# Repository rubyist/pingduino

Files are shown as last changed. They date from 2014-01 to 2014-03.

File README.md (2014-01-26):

# Pingduino

Pingduino an Arduino based score keeper for games of ping pong. This repository
contains everything you need to build your own. Except the hardware, of course!

## Features

Pingduino is set up such that there are two scoring buttons and a display. I've
mounted the buttons underneath my ping pong table, one on each side. When a player
scores, they press their button.

The display is built to show each score and an indicator showing whose who is
currently serving. The serve indicator updates automatically as scores are input.

The program code contains game winning logic, meaning it knows the rules of
ping pong and will indicate the winner when it detects the game has been won.

Upon detecting a win, Pingduino will play a victory song and flash the serve
indicator of the game winner.

If Pingduino detects no activity for 20 minutes it will automatically turn off
the display lights and the scoring button lights. Pressing any button will wake
the display and Pingduino will pick up where you left off.

## Usage Instructions

Once you've built and installed Pingduino it's time to play! Simply start playing
ping pong. Pingduino lets you know which player should serve. If you score, press
your button. Eventually somebody will win!

Once the game has been won, the player who will serve the next game will reset
the system by doing a long press (press and hold for a second or two) on their
button.

## Building Your Own

Building your own Pingduino should be easy. It's my first Arduino project and
I'm a pretty novice hardware hacker. This repository contains the program code
to load onto the Arduino as well as schematics, a parts list, and a PCB layout
should you choose to go beyond the breadboard. Once completed I'll post a link
to pictures of my build process.

### Display

I was initially going to use some giant ~8" 7-segment LEDs for the score display,
however the two that I found that were big enough were too expensive and not well
built or out of stock. I decided to build my own large 7-segment displays out of
ping pong balls and individual LEDs. Once assembled, these behave pretty much like
regular 7-segment displays and I'm driving them with 4 shift registers chained
together.

I've kept the display logic code fairly encapsulated so that you can be free to
implement whatever kind of display you'd like. My intitial prototypes were built
using an LCD display.

### Scoring Buttons

There are scoring buttons mounted under each side of the table. I used some
[big dome push buttons](https://www.sparkfun.com/products/11275) from Sparkfun.
These are pretty big, you could certainly get away with much smaller buttons,
but I ordered them so I rolled with it.

To connect the buttons to the main module I used some 1/8" audio jacks and cables.
These are readily available, cheap, and perfectly support the button signal and
a line to light the LED in the button.

To mount the buttons under the table I designed and printed some simple boxes.
You can find the openscad and stl files in the models directory. I printed these
on a Makerbot Replicator 2. It's just a box that goes under a table so you can
get away with printing at a lower resolution (0.3mm), but be aware that the hole
for the audio jack will probably have to be drilled and smoothed out some before
it fits nicely.

## Contributing

Got an idea for improving Pingduino? Found a bug? I'd love to know about it!
Simply file an issue or open a pull request here on GitHub.

If you build and use a Pingduino I'd love to know about it, especially if you
come up with a different kind of display.

## License

Everything in this repo is released under the MIT license.

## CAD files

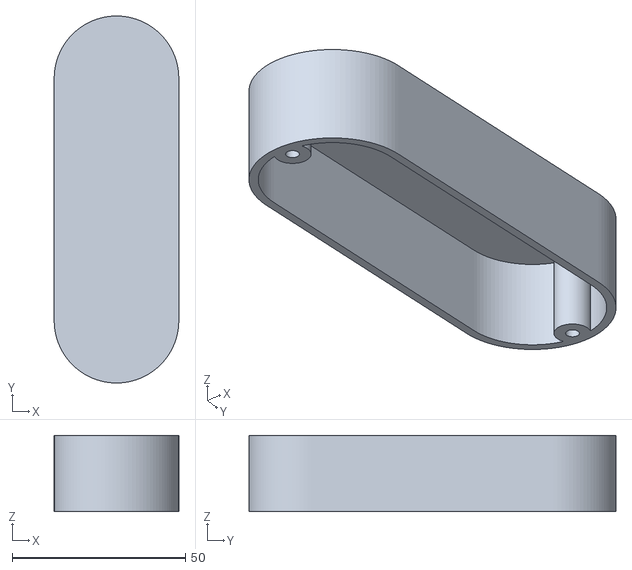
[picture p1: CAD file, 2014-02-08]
models/segment.stl
36.0 x 106.0 x 22.0

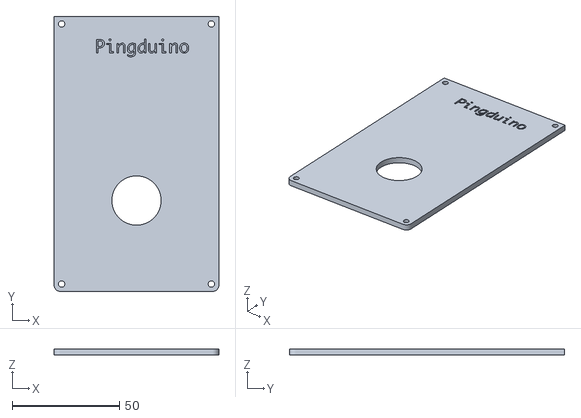
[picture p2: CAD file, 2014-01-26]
models/switch-mount-cover.stl
77.0 x 128.5 x 3.00

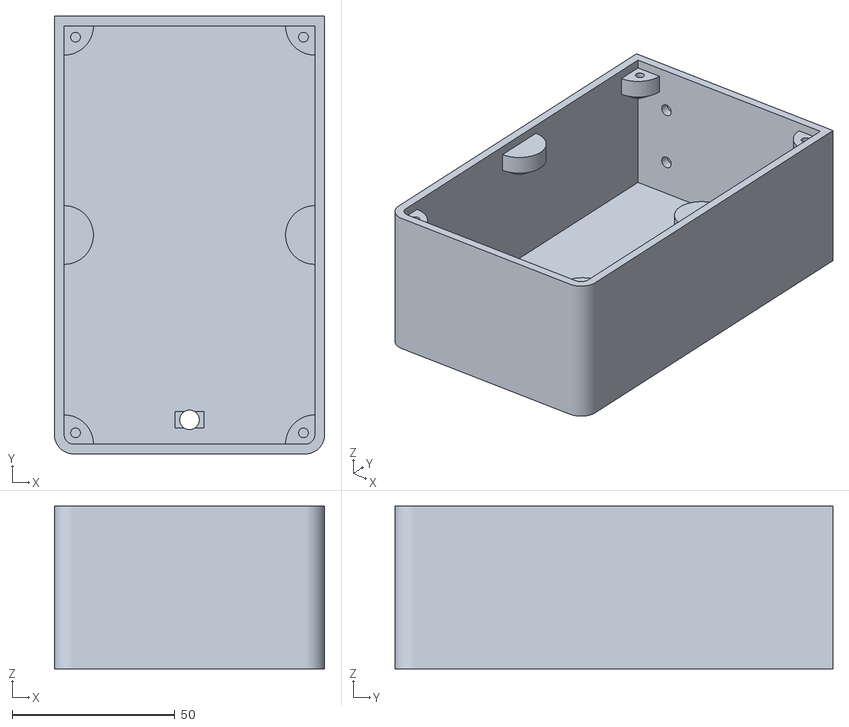
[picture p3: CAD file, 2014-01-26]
models/switch-mount.stl
83.0 x 134.5 x 50.0

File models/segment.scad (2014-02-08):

radius = 18;
height = 22;
length = 70;
wall   =  2;

$fn=100;

module post() {
    difference() {
        cylinder(r=4, h=height-wall);
        cylinder(r=1.5, h=10);
    }
}

difference() {
    hull() {
        cylinder(r=radius, h=height);

        translate([0, length, 0])
        cylinder(r=radius, h=height);
    }

    hull() {
        translate(0, wall, 0)
        cylinder(r=radius-wall, h=height-wall);

        translate([0, length, 0])
        cylinder(r=radius-wall, h=height-wall);
    }
}

translate([0, -(radius+wall)/2-2*wall, 0])
post();

translate([0, length + ((radius+wall)/2+2*wall), 0])
post();

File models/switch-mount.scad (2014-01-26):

// This box is the housing for the scoring buttons that get mounted
// under the pingpong table. The buttons I used are these:
// https://www.sparkfun.com/products/11275
// In hindsight, these buttons are rather large. You could use smaller
// buttons and adjust some of these values accordingly.

// The overall radius of the button. The datasheet reports 100mm, but
// mine both measure 98.
button_radius = 49;

// The radius of the hole the button back needs.
hole_radius = 11.5;

// There's a bar on the front of my table that is 40mm high
table_padding = 40;

// I want 30mm around the button's hole
bottom_padding = 30;
extra_padding = 4;

// The thickness of the box walls
wall_thickness = 3;

// Dimensions for the overall box
mount_height = table_padding + extra_padding + button_radius + hole_radius + bottom_padding;
mount_depth = 50;
mount_width = (hole_radius * 2) + (bottom_padding * 2);

$fn=100;
font = "monaco.dxf";

// Comment or uncomment the body or cover, depending on which you need to render

// Body
union() {
    difference() {
        bottom();
        // You can inscribe something here. I print the box at lower resolution (.3mm), it
        // comes out OK but not very good looking. Higher res looks better.
        // name();
    }
    
    difference() {
        sides();
        cover_screws();
        mount_screws();
    }
}

// Cover
/*
difference() {
    translate([0, 0, mount_depth-wall_thickness])
    cover();
    cover_screws();
    // Remove this line if you don't want the project's name on the cover
    project();
}
*/

// You shouldn't have to configure anything below this, except maybe text
// attributes at the bottom if you're putting your own text in it.

module bottom() {
    difference() {
    hull() {
        // lower left
        translate([wall_thickness*2, wall_thickness*2, 0])
        cylinder(r=wall_thickness*2, h=wall_thickness);
        
        // lower right
        translate([mount_width-(wall_thickness*2), wall_thickness*2, 0])
        cylinder(r=wall_thickness*2, h=wall_thickness);

        // upper right
        translate([mount_width-(wall_thickness*2), mount_height-(wall_thickness*2), 0])
        cube(size=[wall_thickness*2, wall_thickness*2, wall_thickness]);
        
        // upper left
        translate([0, mount_height-(wall_thickness*2), 0])
        cube(size=[wall_thickness*2, wall_thickness*2, wall_thickness]);
    }

    union() {
        translate([mount_width/2, wall_thickness+7.5, -1])
        cylinder(r=3, h=wall_thickness+2);

        translate([mount_width/2-4.5, wall_thickness+7.5-2.5, wall_thickness-.8])
        cube(size=[9, 5, 1]);
    }
    }
}

module sides() {
    difference() {
        hull() {
            // lower left
            translate([wall_thickness*2, wall_thickness*2, 0])
            cylinder(r=wall_thickness*2, h=mount_depth);
            
            // lower right
            translate([mount_width-(wall_thickness*2), wall_thickness*2, 0])
            cylinder(r=wall_thickness*2, h=mount_depth);

            // upper right
            translate([mount_width-(wall_thickness*2), mount_height-(wall_thickness*2), 0])
            cube(size=[wall_thickness*2, wall_thickness*2, mount_depth]);
            
            // upper left
            translate([0, mount_height-(wall_thickness*2), 0])
            cube(size=[wall_thickness*2, wall_thickness*2, mount_depth]);
        }
        
        hull() {
            // lower left
            translate([wall_thickness*2, wall_thickness*2, 0])
            cylinder(r=wall_thickness, h=mount_depth+1);
            
            // lower right
            translate([mount_width-(wall_thickness*2), wall_thickness*2, 0])
            cylinder(r=wall_thickness, h=mount_depth+1);

            // upper right
            translate([mount_width-(wall_thickness*2), mount_height-(wall_thickness*2), 0])
            cube(size=[wall_thickness, wall_thickness, mount_depth+1]);
            
            // upper left
            translate([wall_thickness, mount_height-(wall_thickness*2), 0])
            cube(size=[wall_thickness, wall_thickness, mount_depth+1]);
        }
    }

    intersection() {
        translate([wall_thickness, wall_thickness, 0])
        cube([mount_width-(wall_thickness*2), mount_height-(wall_thickness*2), mount_depth]);

        union() {
            translate([wall_thickness, wall_thickness, mount_depth-6-wall_thickness])
            cylinder(r=9, h=6);
            translate([wall_thickness, wall_thickness, mount_depth-10-wall_thickness])
            cylinder(r1=3, r2=9, h=4);

            translate([wall_thickness, mount_height/2, mount_depth-6-wall_thickness])
            cylinder(r=9, h=6);
            translate([wall_thickness, mount_height/2, mount_depth-10-wall_thickness])
            cylinder(r1=3, r2=9, h=4);

            translate([mount_width-wall_thickness, wall_thickness, mount_depth-6-wall_thickness])
            cylinder(r=9, h=6);
            translate([mount_width-wall_thickness, wall_thickness, mount_depth-10-wall_thickness])
            cylinder(r1=3, r2=9, h=4);

            translate([mount_width-wall_thickness, mount_height/2, mount_depth-6-wall_thickness])
            cylinder(r=9, h=6);
            translate([mount_width-wall_thickness, mount_height/2, mount_depth-10-wall_thickness])
            cylinder(r1=3, r2=9, h=4);

            translate([mount_width-wall_thickness, mount_height-wall_thickness, mount_depth-6-wall_thickness])
            cylinder(r=9, h=6);
            translate([mount_width-wall_thickness, mount_height-wall_thickness, mount_depth-10-wall_thickness])
            cylinder(r1=3, r2=9, h=4);

            translate([wall_thickness, mount_height-wall_thickness, mount_depth-6-wall_thickness])
            cylinder(r=9, h=6);
            translate([wall_thickness, mount_height-wall_thickness, mount_depth-10-wall_thickness])
            cylinder(r1=3, r2=9, h=4);
        }
    }
}

module cover() {
    hole_center = mount_height - table_padding - button_radius;

    difference() {
        hull() {
            // lower left
            translate([wall_thickness*2, wall_thickness*2, 0])
            cylinder(r=wall_thickness, h=wall_thickness);
            
            // lower right
            translate([mount_width-(wall_thickness*2), wall_thickness*2, 0])
            cylinder(r=wall_thickness, h=wall_thickness);
            
            // upper right
            translate([mount_width-(wall_thickness*2), mount_height-(wall_thickness*2), 0])
            cube(size=[wall_thickness, wall_thickness, wall_thickness]);
            
            // upper left
            translate([wall_thickness, mount_height-(wall_thickness*2), 0])
            cube(size=[wall_thickness, wall_thickness, wall_thickness]);
        }
        
        translate([mount_width/2, hole_center, -1])
        cylinder(r=hole_radius, h=wall_thickness*2);
    }

    // Fake button
    // translate([mount_width/2, hole_center, 5])
    // cylinder(r=button_radius, h=20);
}

module cover_screws() {
    translate([wall_thickness+3.5, wall_thickness+3.5, mount_depth/2])
    cylinder(r=1.5, h=30);

    translate([mount_width-wall_thickness-3.5, wall_thickness+3.5, mount_depth/2])
    cylinder(r=1.5, h=30);

    translate([mount_width-wall_thickness-3.5, mount_height-wall_thickness-3.5, mount_depth/2])
    cylinder(r=1.5, h=30);

    translate([wall_thickness+3.5, mount_height-wall_thickness-3.5, mount_depth/2])
    cylinder(r=1.5, h=30);
}

module mount_screws() {
    spacing = 15;
    
    translate([spacing, mount_height, spacing])
    rotate([90, 0, 0])
    cylinder(r=2, h=wall_thickness+2);

    translate([spacing, mount_height, mount_depth-spacing])
    rotate([90, 0, 0])
    cylinder(r=2, h=wall_thickness+2);

    translate([mount_width-spacing, mount_height, mount_depth-spacing])
    rotate([90, 0, 0])
    cylinder(r=2, h=wall_thickness+2);

    translate([mount_width-spacing, mount_height, spacing])
    rotate([90, 0, 0])
    cylinder(r=2, h=wall_thickness+2);
}

// Text
module letter(l, h=100, i=0) {
    union() {
        linear_extrude(height=h) import(font, layer=l[i]);
        translate([dxf_dim(file=font, name="advx", layer=l[i]), dxf_dim(file=font, name="advy", layer=l[i]), 0])
        child();
    }
}

module word(wrd, h=100, i=0) {
    if (i < len(wrd)) {
        letter(wrd, h, i) word(wrd, h, i+1);
    } else {
        child();
    }
}


module name() {
    translate([18.5, mount_height - 20, wall_thickness-1.5])
    scale(0.002)
    word("YourTextHere", 1000);
}

module project() {
    translate([22, mount_height-20, mount_depth-1.5])
    scale(0.002)
     word("Pingduino", 1000);
}

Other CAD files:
models/monaco.dxf

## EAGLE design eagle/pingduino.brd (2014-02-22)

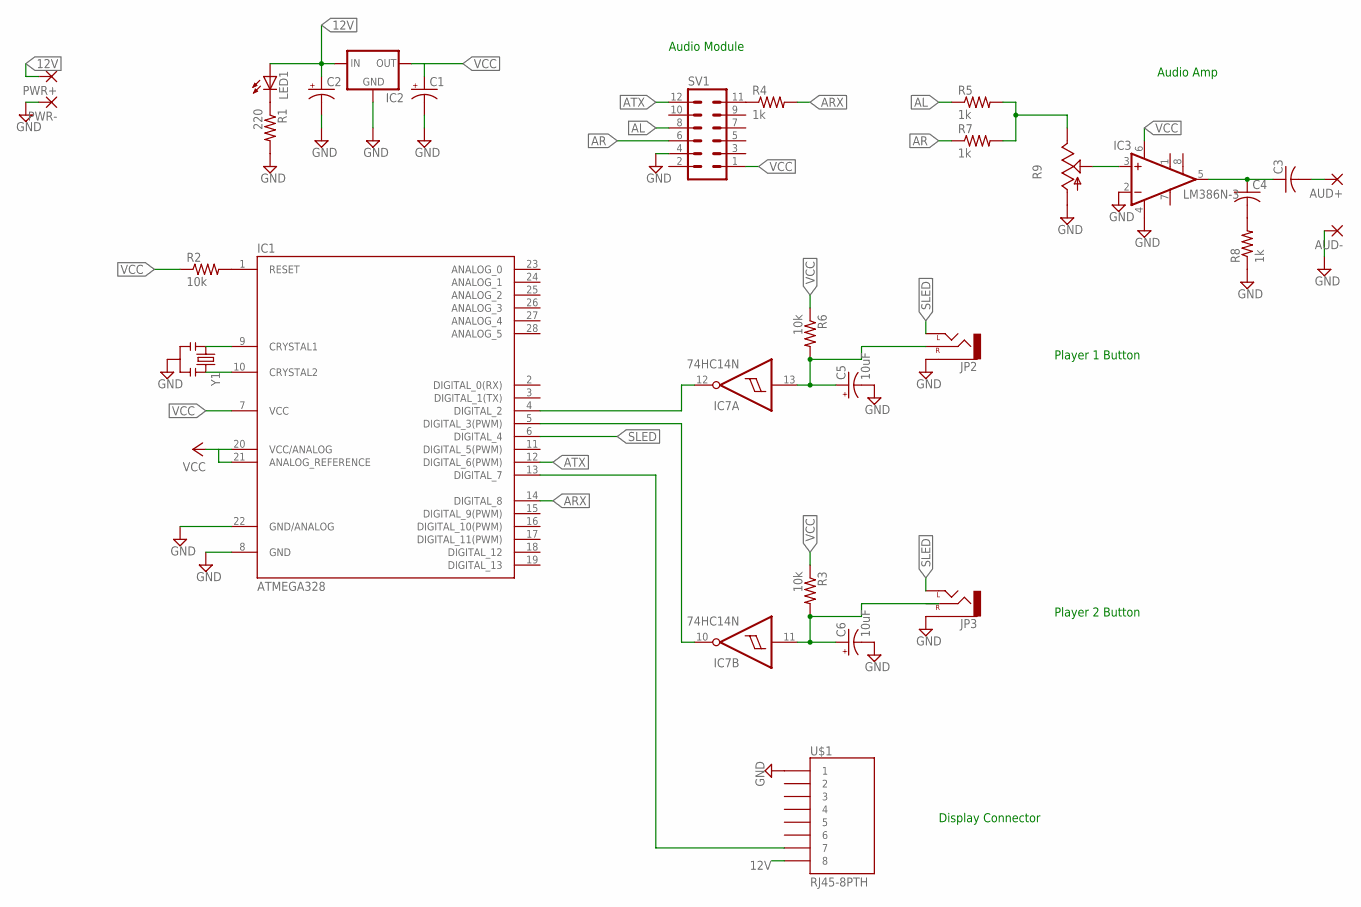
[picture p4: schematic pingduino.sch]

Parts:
AUD+: WIREPAD2,15/1,0; 2,15/1,0
AUD-: WIREPAD2,15/1,0; 2,15/1,0
C1, C2: CAP_POLPTH2; CPOL-RADIAL-10UF-25V
C3, C4: C-US050-024X044; C050-024X044
C5, C6: 10uF; CPOL-RADIAL-10UF-25V
IC1: ATMEGA328; DIL28-3
IC2: V_REG_78XX-TO-220; TO-220-ALT
IC3: LM386N-3; DIL08
IC7: 74HC14N; DIL14
JP2, JP3: AUDIO-JACKPTH; AUDIO-JACK
LED1: LED3MM
PWR+: WIREPAD2,15/1,0; 2,15/1,0
PWR-: WIREPAD2,15/1,0; 2,15/1,0
R1: 220; 0204/7
R2, R3, R6: 10k; 0204/7
R4, R5, R7, R8: 1k; 0204/7
R9: TRIM_US-B25U; B25U
SV1: MA06-2
U$1: RJ45-8PTH; RJ45-8
Y1: RESONATORPTH; RESONATOR-PTH

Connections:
12V: C2.1 (+), IC2.IN, LED1.A, PWR+.1, U$1.8
AL: R5.1, SV1.8
AR: R7.1, SV1.6
ARX: IC1.13 (DIGITAL_7), IC1.14 (DIGITAL_8), R4.2, U$1.7
ATX: IC1.12 (DIGITAL_6(PWM)), SV1.12
GND: AUD-.1, C1.2 (-), C2.2 (-), C5.2 (-), C6.2 (-), IC1.8 (GND), IC1.22 (GND/ANALOG), IC2.GND, IC3.2 (-IN), IC3.4 (GND), IC7.7 (GND), JP2.SLEEVE, JP3.SLEEVE, PWR-.1, R1.2, R8.1, R9.A, SV1.4, U$1.1, Y1.2
unnamed: IC1.10 (CRYSTAL2), Y1.3
unnamed: IC1.9 (CRYSTAL1), Y1.1
unnamed: LED1.K (C), R1.1
unnamed: IC1.1 (RESET), R2.2
unnamed: IC1.4 (DIGITAL_2), IC7.12 (O)
unnamed: C6.1 (+), IC7.11 (I), R3.2
unnamed: IC1.5 (DIGITAL_3(PWM)), IC7.10 (O)
unnamed: C5.1 (+), IC7.13 (I), JP2.RING (RIGHT), R6.2
unnamed: R4.1, SV1.11
unnamed: R5.2, R7.2, R9.E
unnamed: IC3.3 (+IN), R9.S
unnamed: C3.1, C4.1, IC3.5 (OUT)
unnamed: C4.2, R8.2
unnamed: AUD+.1, C3.2
SLED: IC1.6 (DIGITAL_4), JP2.TIP (LEFT), JP3.TIP (LEFT)
VCC: C1.1 (+), IC1.7 (VCC), IC1.20 (VCC/ANALOG), IC1.21 (ANALOG_REFERENCE), IC2.OUT, IC3.6 (VS), IC7.14 (VCC), R2.1, R3.1, R6.1, SV1.1

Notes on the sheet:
Player 1 Button
Player 2 Button
Display Connector
Audio Module
Audio Amp

Board: 2 copper layers, 29 parts (0 on the bottom side), 22 nets, no tracks yet.

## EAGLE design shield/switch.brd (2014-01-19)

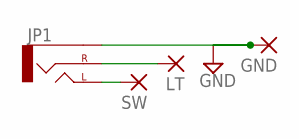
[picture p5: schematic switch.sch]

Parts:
GND: 2,15/1,0
JP1: AUDIO-JACKPTH; AUDIO-JACK
LT: 2,15/1,0
SW: 2,15/1,0

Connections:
GND: GND.1, JP1.SLEEVE
unnamed: JP1.RING (RIGHT), LT.1
unnamed: JP1.TIP (LEFT), SW.1

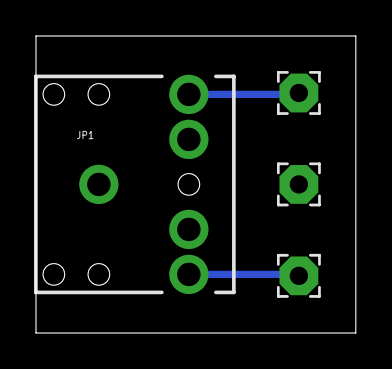
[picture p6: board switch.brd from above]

Board: 2 copper layers, 17.8 x 16.5 mm, 4 parts (0 on the bottom side), 3 nets.

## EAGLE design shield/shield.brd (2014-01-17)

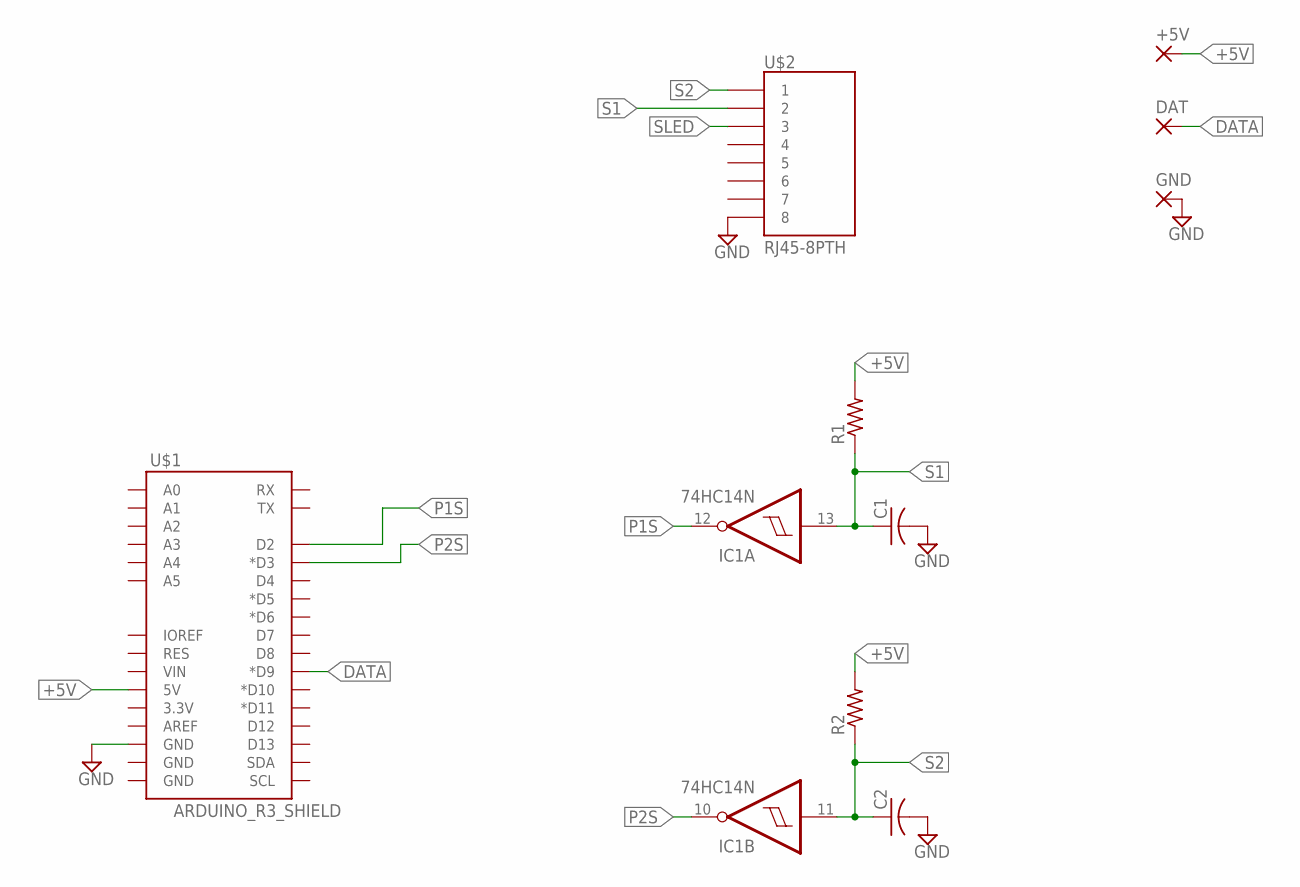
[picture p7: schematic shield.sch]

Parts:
+5V: WIREPAD2,15/1,0; 2,15/1,0
C1, C2: C-US025-025X050; C025-025X050
DAT: WIREPAD2,15/1,0; 2,15/1,0
GND: WIREPAD2,15/1,0; 2,15/1,0
IC1: 74HC14N; DIL14
R1, R2: R-US_0207/7; 0207/7
U$1: ARDUINO_R3_SHIELD; UNO_R3_SHIELD
U$2: RJ45-8PTH; RJ45-8

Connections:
+5V: +5V.1, R1.2, R2.2, U$1.5V
DATA: DAT.1, U$1.D9 (*D9)
GND: C1.2, C2.2, GND.1, IC1.7 (GND), U$1.GND@2 (GND), U$2.8
P1S: IC1.12 (O), U$1.D2
P2S: IC1.10 (O), U$1.D3 (*D3)
S1: C1.1, IC1.13 (I), R1.1, U$2.2
S2: C2.1, IC1.11 (I), R2.1, U$2.1
SLED: U$2.3
VCC: IC1.14 (VCC)

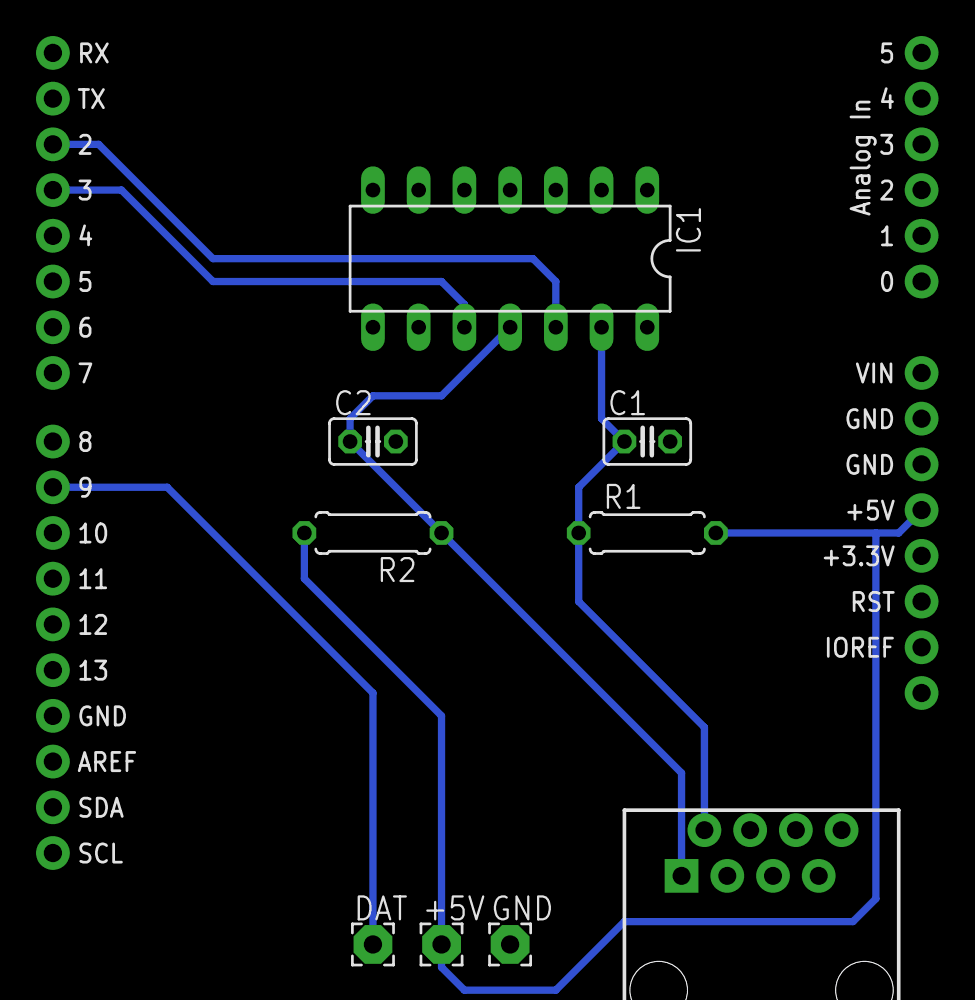
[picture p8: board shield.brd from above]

Board: 2 copper layers, 10 parts (0 on the bottom side), 7 nets.

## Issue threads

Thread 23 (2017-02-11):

basketball 24 sec shotclock

joemxwolf, 2017-02-11:
Good day sir! I wish you can help me to run the codes for the 24 shotclock countdown. i already have the code for the countdown but i wish to have buttons to reset, start/stop and 14 sec. i will have a wifi to wifi connection. my problem is i don't know how to set up the project. i only have the loop for the countdown. what will i do next sir? i use sk6812 led strip and the fastled lib. hoping for your response sir! Big thanks!

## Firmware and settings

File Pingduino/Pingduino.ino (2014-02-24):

#include <Adafruit_NeoPixel.h>
#include <SoftwareSerial.h>
#include <Garan.h>

#include "Button.h"
#include "Game.h"
#include "Display.h"

#define P1PIN           2
#define P2PIN           3
#define LONGPRESS_TIME  1000
#define INACTIVEMILLIS  1200000 // 20 minutes
#define AUDIOTX         6
#define AUDIORX         8

// Game Logics
int p1Score = 0;
int p2Score = 0;
int requestReset = 0; // 0 = nobody, 1 = p1, 2 = p2
unsigned long lastActivityTime;

boolean sleeping = false;
boolean winSent = false;

Button p1Button(P1PIN);
Button p2Button(P2PIN);

Game game;
Display display;

SoftwareSerial garanSerial(AUDIOTX, AUDIORX);
Garan songPlayer(garanSerial);


void setup()
{
  Serial.begin(9600);
  
  p1Button.setPressCallback(p1ButtonPressed);
  p1Button.setLongPressCallback(p1ResetRequest);
  p1Button.setDoublePressCallback(p1DecrementScore);
  
  p2Button.setPressCallback(p2ButtonPressed);
  p2Button.setLongPressCallback(p2ResetRequest);
  p2Button.setDoublePressCallback(p2DecrementScore);

  game.init();
  display.init();
  display.refresh(game);
  
  lastActivityTime = millis();
  Serial.println("dbg: Initialized");
}

void p1ButtonPressed()
{
  lastActivityTime = millis();
  if (sleeping) return;
  if (game.over()) return;
  
  Serial.println("score: 1,1");
  p1Score++;
}

void p1ResetRequest()
{
  lastActivityTime = millis();
  if (sleeping) return;

  Serial.println("reset: 1");
  requestReset = 1;
}

void p1DecrementScore() {
  lastActivityTime = millis();
  if (sleeping) return;
  if (game.over()) return;

  if (p1Score > 0) {
    Serial.println("score: 1,-1");
    p1Score--;
  }
}

void p2ButtonPressed()
{
  lastActivityTime = millis();
  if (sleeping) return;
  if (game.over()) return;
  
  Serial.println("score: 2,1");
  p2Score++;
}

void p2ResetRequest()
{
  lastActivityTime = millis();
  if (sleeping) return;

  Serial.println("reset: 2");
  requestReset = 2;
}

void p2DecrementScore() {
  lastActivityTime = millis();
  if (sleeping) return;
  if (game.over()) return;

  if (p2Score > 0) {
    Serial.println("score: 2,-1");
    p2Score--;
  }
}

void loop()
{
  // The loop will:

  // Poll the scoring buttons
  p1Button.tick();
  p2Button.tick();
  
  // Check whether it should go to sleep or wake up
  if ((millis() - lastActivityTime) > INACTIVEMILLIS) {
    goToSleep();
  } else {
    wakeup();
  }

  if (sleeping)
    return;

  // Update the game
  game.updateScore(p1Score, p2Score);

  // Show the score
  display.refresh(game);

  // Send game over event
  if (game.over() && !winSent) {
    songPlayer.singlePlay(1);
    Serial.print("win: ");
    Serial.print(p1Score);
    Serial.print(",");
    Serial.println(p2Score);
    winSent = true;
  }

  // Handle game reset
  if (requestReset > 0) {
    game.restart(requestReset);
    p1Score = p2Score = 0;
    requestReset = 0;
    winSent = false;
    songPlayer.stop();
  }
  
  delay(20);
}

void goToSleep()
{
  if (sleeping) return;
  sleeping = true;
  display.sleep();
  Serial.println("dbg: Going to sleep.");
}

 void wakeup()
 {
   if (!sleeping) return;
   
   sleeping = false;
   Serial.println("dbg: Waking up.");
 }

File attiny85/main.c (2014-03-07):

#include <avr/io.h>
#include <avr/interrupt.h>
#include <util/delay.h>
#include <stdlib.h>

#include "display.h"
#include "button.h"

/*
PB0 - button leds
PB1 - display
PB2 - unassigned
PB3 - p1 score
PB4 - p2 score
PB5 - unassigned
*/

#define P1BUTTON  PB3
#define P2BUTTON  PB4
#define BUTTONLED PB0

#define WINLED PB2 // temp

int main(void) {
  uint8_t p1Score = 0;
  uint8_t p2Score = 0;

  Button p1Button = new_button(P1BUTTON);
  Button p2Button = new_button(P2BUTTON);

  DDRB |= (1 << BUTTONLED);
  DDRB |= (1 << WINLED); // temp

  PORTB |= (1 << P1BUTTON) | (1 << P2BUTTON);
  PORTB &= ~(1 << WINLED); // temp

  CLKPR=_BV(CLKPCE);
  CLKPR=0;

  TCCR1 |= (1 << CS10) | (1 << CS11);// | (1 << CS12 ) || (0 << CS13);
  TCNT1 = 0;

  while (1) {
    // Poll buttons for scoring
    switch (button_tick(p1Button)) {
      case SinglePress:
        p1Score++;
        break;
      default:
        break;
    }

    switch (button_tick(p2Button)) {
      case SinglePress:
        p2Score++;
        break;
      default:
        break;
    }


    // Update score display
    display_score(p1Score, p2Score);


    // Check for a game win scenario
    if ((p1Score >= 11 || p2Score >= 11) && abs(p1Score - p2Score) >= 2) {
      // Game is over
      PORTB |= (1 << WINLED); // temp
    }


    // _delay_ms(10);
  }
  return (0);
}

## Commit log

2013-12-22 Count button presses for score tracking
2013-12-22 oo'ify button handlers
2013-12-23 Keep track of serves
2014-01-04 Put button lights on pins, sleep/wake them up too
2014-01-06 import eagle schematics
    [pingduino.sch]
2014-01-07 Fix display connectors on schematic
    [pingduino.sch]
2014-01-07 First attempt at pcb layout
    [pingduino.brd]
2014-01-08 Re-route the 5x2 headers so I can actually solder them.
    [pingduino.brd]
2014-01-11 Convert the code to the current schematic, use of hardware interrupts
2014-01-11 Handle game over / reset
    [Pingduino.ino]
2014-01-11 Remove serial printing
2014-01-11 Don't reset the variable before you pass it in to game.reset() ...
    [Pingduino.ino]
2014-01-11 When game is reset, interrupt the victory song
    [Pingduino.ino]
2014-01-17 Start work on schematics/board for an arduino shield version with a different display idea
    [shield.brd, shield.sch]
2014-01-19 Sketchup model for under table switch mount
    [switch-mount.skp]
2014-01-19 Board/Schematic for switch mounts
    [switch.brd, switch.sch]
2014-01-19 fix ground plane routing on switch mount board
    [switch.brd, switch.sch]
2014-01-21 Stop the song on reset, make sure song can play again
    [Pingduino.ino]
2014-01-21 player one score on the led strip
2014-01-22 Display functions for all players.
    - use 2 leds per segment
    - disable button leds for now, I think it's drawing too much current
    [Pingduino.ino]
2014-01-24 Use polling for buttons as interrupts were problematic with the wave shield
    [Pingduino.ino]
2014-01-24 Double pressing a button will decrement the score
2014-01-24 Allow mid-game reset. Closes #11
    [Pingduino.ino]
2014-01-24 Fix sleep and wake up
    [Pingduino.ino]
2014-01-25 Start a redo of the switch mount in openscad
    [switch-mount.scad]
2014-01-25 more mounts, fix screws
    [switch-mount.scad]
2014-01-25 mounting screws
    [switch-mount.scad]
2014-01-25 Comments, STL exports for mount body and cover
    [switch-mount-cover.stl, switch-mount.scad, switch-mount.stl]
2014-01-25 remove old sketchup model
    [switch-mount.skp]
2014-01-25 Thinner walls
    [switch-mount-cover.stl, switch-mount.scad, switch-mount.stl]
2014-01-25 Show body by default
    [switch-mount.scad]
2014-01-25 Add some commenting to the switch mount scad file
    [switch-mount.scad]
2014-01-25 Correct hole diameter in button box
    [switch-mount.scad]
2014-01-26 remove unused code
    [switch-mount.scad]
2014-01-26 Add a couple supports midway up the box
    [switch-mount.scad]
2014-01-26 Remove name printing
    [switch-mount.scad]
2014-01-26 Need a little extra padding for my table
    [switch-mount.scad]
2014-01-26 Update stl files
    [switch-mount-cover.stl, switch-mount.stl]
2014-01-26 Readme blurb about the buttons and boxes
2014-01-30 Display segment scad file
    [segment.scad]
2014-01-30 enshorten the segments a bit
    [segment.scad]
2014-01-30 segment stl
    [segment.stl]
2014-02-08 Designate debug serial prints vs game play A Raspberry Pi or other device can be hooked to the serial port and watch for these events. This can be used to track statistics, provide a web app, tournam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
2014-02-08 Update segment model
    [segment.scad, segment.stl]
2014-02-22 Add Garan audio module and amplifier to schematic and board
    [pingduino.brd, pingduino.sch]
2014-03-05 Rudimentary scoring button code Does not yet contain the state machine for short/long/double pressing
    [main.c]
2014-03-05 turn on the score button leds
2014-03-07 Sketch in button handling, still needs timer work

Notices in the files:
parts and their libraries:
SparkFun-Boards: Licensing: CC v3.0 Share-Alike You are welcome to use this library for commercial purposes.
